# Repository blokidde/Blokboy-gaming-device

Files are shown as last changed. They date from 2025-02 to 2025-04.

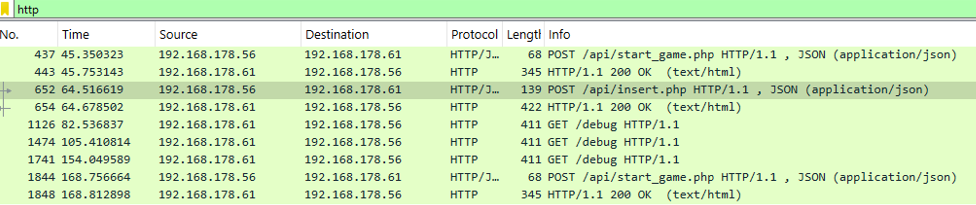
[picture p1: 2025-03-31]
docs/assets/http_messages.png

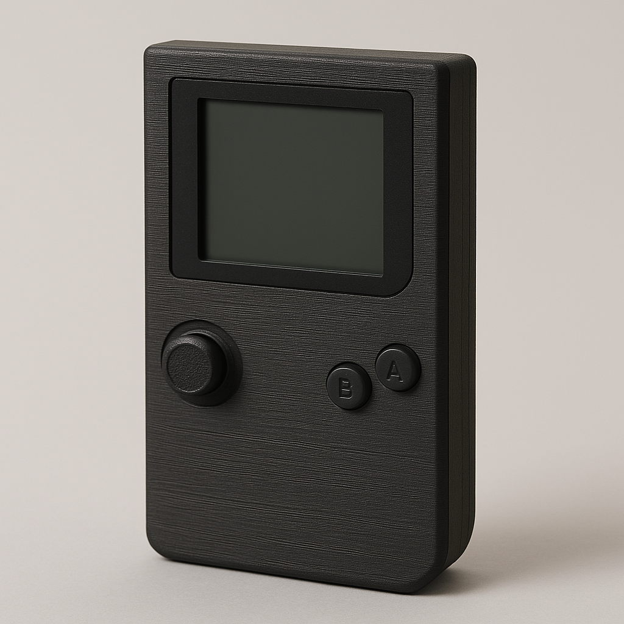
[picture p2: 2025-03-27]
docs/assets/3d_generated_blockboy_picture.png

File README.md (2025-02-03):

# IoT Start Project

This is your IoT Gitlab project. You can use it to store your code and documentation. 

## Getting Started

This project contains a setup using Docker. This will help you setup all the necessary tools to start developing your IoT project.
Before you run the docker-compose command, make sure you have to make changes to the configuration. You can find these in
the `.env` file.

Now, to install and start your project; run the following command in the root of your project:

```bash
docker-compose up -d
```

If everything runs correctly, you should be able to visit your website at [http://localhost/](http://localhost/).

## Structure

There is a specific structure that you should follow when developing your project. This will help you to keep your project organized and easy to understand.

**Documentation**

All the documentation of your project should be placed in the `docs/` folder. This will be used for your portfolio-website.

```bash
├── docs/
```

**Embedded**

Everything you need to run your embedded application should be placed in the `embedded/` folder. This includes the source code like .ino-files from Arduino.

```bash
├── embedded/
```

**Web**

Everything you need to run your web application should be placed in the `web/` folder. This includes the source code like PHP, HTML, CSS, Javascript and images.

```bash
├── web/
```

You can visit your website by going to [http://localhost/](http://localhost/) in your browser. And you can find your IoT dashboard at [http://localhost/dashboard](http://localhost/dashboard).

## Database details

The database is a MySQL database using MariaDB. You can connect to it using the following details:

| Parameter | Value |
| --- | --- |
| Host | `mariadb` (from PHP) `localhost` (from your laptop) |
| Port | `3306` |
| Username | `root` |
| Password | You can find this in your .env-file. |
| Database | You need to create the database yourself. |

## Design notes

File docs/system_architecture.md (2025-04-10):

# System Architecture

## Introduction
This section provides an overview of the entire IoT Snake Game setup. It explains each hardware and software component and how they communicate.

## Legend
- Rectangles: Subsystems or containers  
- Components: Smaller software units (for example, code files and libraries)  
- Database symbol: Data storage  
- Cloud symbols: External systems (for instance, GitLab or the Internet)  
- Arrows: Show direction of data and the communication protocols (HTTP, MySQL, etc.)

## Architecture Diagram
The following image shows the System Architecture Diagram for the IoT Snake Game. Each subsystem is labeled, and communication lines show which protocols and ports are used.

Architecture_Diagram

## Subsystems and Components

1. User Device (Mobile / Laptop)  
   - Runs a Browser that displays the frontend (HTML, CSS, JavaScript).  
   - Sends HTTP debug requests to the ESP32.  
   - Receives pages and data from the NGINX web server (HTTPS).

2. Host System (PC / Laptop)  
   - Runs the Docker Host with multiple containers (NGINX, PHP, MariaDB, phpMyAdmin).  
   - Connects to GitLab (external repository) and the Docker Registry (external system) to pull Docker images.  
   - Uses the Host OS (Windows/Linux) as the operating system.

3. Web Server (NGINX)  
   - Main entry point for HTTPS traffic from the browser.  
   - Hosts the Frontend (HTML, CSS, JS files).  
   - Routes API calls to the Backend (PHP scripts).

4. Backend (PHP API)  
   - Handles requests via API PHP files (for example, insert.php, get.php).  
   - Uses Backend Libraries (native PHP functions or extensions) to process data.  
   - Connects to the database for storing and retrieving game information.

5. Database System  
   - Runs inside the MariaDB Container.  
   - Holds the MariaDB Database and the Database Instance (actual data).  
   - Stores player scores and any other relevant game data.

6. Embedded System (ESP32)  
   - Written in C++ with Arduino Libraries.  
   - Contains the Game Logic for the Snake Game and an HTTP Client for sending and receiving data.  
   - Interfaces with the Joystick, Button, Buzzer, and TFT Display.

7. External Systems  
   - Internet / Intranet: Used for network communication (HTTPS, etc.).  
   - GitLab Repository: Stores the project code (external system).  
   - Docker Registry: Hosts Docker images (external system).

## Communication Protocols
- HTTPS (443): Browser to NGINX (secure)  
- HTTP (80): ESP32 to Backend or for debug requests  
- MySQL (3306): Backend (API) to database  
- SPI: ESP32 to TFT display  
- Analog / Digital: Joystick and button inputs  
- PWM: Buzzer output from ESP32

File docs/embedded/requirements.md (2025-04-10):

# Requirements

# requirements EMBRQ#01
The embedded device acts as a client and sends measured sensor data to the application backend over http or https.

## EMBRQ#01
The ESP32 sends sensor data to a webserver using HTTPS. It acts like a client and sends the number of times the joystick was moved up, down, left, and right. This is done using WiFi and a POST request. The data is sent as a JSON string to the backend. more aboout this can be read in the research page

### Code:
```cpp
WiFiClientSecure client;
client.setInsecure();

HTTPClient httpClient;
httpClient.begin(client, url);

StaticJsonDocument<200> doc;
doc["totalup"] = totalup;
doc["totaldown"] = totaldown;
doc["totalleft"] = totalleft;
doc["totalright"] = totalright;

String jsonString;
serializeJson(doc, jsonString);

int httpcode = httpClient.POST(jsonString);
```

# requirements EMBRQ#02
The embedded device also acts as a server and receives status messages from the application backend over http or https.

## EMBRQ#02
The ESP32 works as a server. It waits for HTTP requests from the backend. When the backend sends a request to the /debug endpoint, the ESP32 sees this and runs the debug() function. This way, it can receive status messages or commands from the backend over HTTP.

### code
```cpp
WiFiClient client = server.available();

if (client) {
  String request = "";
  while (client.available()) {
    char c = client.read();
    request += c;
    if (c == '\n') break;
  }

  if (request.indexOf("GET /debug") >= 0) {
    debug();
  }
}
```

# requirements EMBRQ#03
The embedded device contains at least two types of input sensors (e.g. LDR, buttons, joystick, capacitive touch, etc.).

## EMBRQ#03
The ESP32 uses two types of input sensors:
- A joystick to control the snake's movement (up, down, left, right).
- Buttons to interact with the game, like starting or restarting.

The joystick is read using analog input pins, and the buttons are read using digital input pins.

### code
example of joystick code:
```cpp
if (vert < DOWNTHRES && snake.direction_y != -1) {
    snake.direction_x = 0;
    snake.direction_y = 1;
}
```

example of button code:
```cpp
while(digitalRead(BUTTON_2_PIN)){
    delay(20);
}
```

# requirements EMBRQ#04
The embedded device contains at least two types of visual and/or sensory outputs (e.g. LED, LED Matrix, 7-segment display, motor, servo, actuator, LCD-screen, buzzer, etc.).

## EMBRQ#04
The ESP32 has two types of outputs:

- An lcd display (ILI9341) that displays the snake game
- A piezo buzzer that makes sound during the debug test and during the game

### code
example for display:
```cpp
Adafruit_ILI9341 display = Adafruit_ILI9341(TFT_CS, TFT_DC, TFT_RST);

display.setTextSize(1);
display.setTextColor(ILI9341_WHITE);
display.fillScreen(ILI9341_BLACK);
```
example for buzzer:
```cpp
tone(BUZZER_PIN, 1000, 100);
```

## requirements EMBRQ#05

The embedded device uses the WifiManager for configuration of SSID and password (PWD) for connecting to the network.

## EMBRQ#05
The esp32 connects to wifi using the wifimanager, it does this by first initializing the library:

### code
```cpp
#include <WiFiManager.h>
```
then the wifimanager checks if it can connect with the wifi with this while loop:
```cpp
if (!wifiManager.autoConnect("ESP32-Setup")) {
  Serial.println("Failed to connect, restarting...");
  delay(3000);
  ESP.restart();
}
```
if it cannot connect, the wifimanager starts a web portal through which you can input the correct wifi.

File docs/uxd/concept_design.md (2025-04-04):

# Concept & Design prototype

## Main goal
the main goal of this project is:  
create a handheld gaming device for playing snake with physical inputs and automatic data tracking, that is fully 3d-printable and works wirelessly. 

## concept
im going to try to make the design look a little like an old gameboy. for designing i used the tool Freecad.

## user description
the user is someone who wants to play a classic snake game on a physical, handheld gaming devie. the user wants to get instant feedback from joystick and button inputs and view scores after a game. the device needs to be small, portable, and easy to charge.

## user needs
- the device must be compact and handheld
- it must feel like an oldschool gameboy
- it must be possible to track gameplay stats
- scores must be sent to a database
- the data should be viewable in a simple online dashboard
- the device must be easy to assemble without tools or glue
- a battery must fit inside so it's fully portable

## product requirements
- the joystick must fit perfectly in the joystickhole
- the screen must be fully visible and centered
- the screen must fit well into the hole, wihtout falling out
- two breadboards with ESP32 and battery must fit inside the case
- the buzzer must fit perfectly in the buzzer hole
- the power button must be accessible from the outside
- all components must be powered by a single li-ion 18650 battery

## first design

frontpanel design:

frontpanel design

in the design for the frontpanel i created several holes. one for the screen, one for the joystick, two push buttons, and an on off button. 

backpanel design:

frontpanel design

on the backpannel you can see two indents, these indents are for 2 breadboards with an esp32 on it and for a li-ion 18650 battery. 

the front and backpanel are suposed to slot together without any glue or screws.

## current design
after 5 iterations of the frontpanel and 2 iterations of the backpanel, all the 3d prints are done and they fit.
the changes that were made are:
- screw pillars
- smaller joystick hole
- bigger on off hole
- direction of screen has changed
- size of screen has changed
- bigger buzzer hole
- bigger battery placement hole

this is the frontpanel:

frontpanel design

this is the backpanel:

frontpanel design

## tools used
for the design part of the project, the following tools and settings were used:

- Freecad for 3d modeling
- exported as STL for slicing
- printed using an Ultimaker 2+ and bambu lab carbon x1 (standard settings)
- filament used: PLA
- layer height: 0.2 mm
- infill: 20%
- supports: only for frontpanel, using the tree support style

i used Freecad because it is open-source and allows full control over design with a nice GUI. this made it easy to quickly change measurements like hole sizes and panel thicknesses during each design.

## recreatability
the device is designed to be fully recreatable:
- freecad files include all versions
- printed with standard PLA and normal 3d printer
- component placement is visible in the 3d model

## versions
### frontpanel
- v1 
- v2 changed sizes for components
- v3 changed small things for component sizes
- v4 rotated display hole, lowered the button holes
- v5 bigger hole for joystick and display, added thicker screw holes

### backpanel
- v1
- v2 more centered and bigger battery hole

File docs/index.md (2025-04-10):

# Blokboy gaming device

This project is a modern version of the classic game called Snake, built with an ESP32 microcontroller and an display. The player controls the snake using a joystick, while their movement data and scores are automatically sent to a server via WiFi.

The web interface displays a scoreboard, showing player IDs and scores in a clean, responsive design. A dedicated debug button allows real-time communication with the ESP32 for testing or troubleshooting. All data is handled through the API and stored in a database, creating a smooth and connected gaming experience.

{{ mdocotion_header('https://images.unsplash.com/photo-1550745165-9bc0b252726f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') }}

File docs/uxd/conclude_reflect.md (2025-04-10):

# Conclude & Reflect

## reflection

### general reflection
this project started with the idea of building a small handheld snake game device that looks like a gameboy. the goal was to make the casing fully 3d printable, without the use of glue or screws, and to make it feel like a polished physical product. through multiple design iterations and test prints, the device became more and more refined. the final result is a working handheld game that is portable, solid, and replicable.

working with Freecad gave me a lot of flexibility, small changes to dimensions were quick and didn’t require starting over completely. 3d printing allowed me to test the physical feel and fit of components in real life, which helped improve the finalization of the design. 

### recommendations for improvements
- improve joystick fit and rotation quality using a custom joystick mount or printed bearing system
- use buttons with larger caps to improve button clarification
- add a small indicator led or animation to show when the device is booting

### failures

#### 1. joystick fit
goal: i wanted the joystick to move freely in all directions without friction  
what went wrong: i made the hole have the same dimensions as the joystick and it was way too big  
how i tried to solve it: i printed several versions with decreased hole diameter  
next time: i would test joystick tolerances with calipers first check the total movement it will need

#### 2. screen visibility
goal: i wnated to create pillars for the joysticks pcb to be attached to  
what went wrong: i created pillars for screws that were too thin   
how i tried to solve it: i made the pillars thicker
next time: i would measure the thickness of the screws i want to use first.

#### 3. first print
goal: i wanted to print my first 3d print
what went wrong: when i tried to print, the fillament didnt stick to the floormat  
how i tried to solve it: i got a teacher to calibrate the 3d printer
next time: there is unfortunately notihing that could be changed about this

#### 4. display spacing
goal: i wanted to put the display in the casing vertically
what went wrong: when i tried to put the display in, it did not fit
how i tried to solve it: i printed a new iteration with the display horizontally

#### all iterations next to eachother
this picture shows all the different iterations starting with the gray ones(bottom) and ending with the final product with the components installed and wired. more can be found about the iterations in the concept design page.

iterations

### final result

the final product works as intended. all parts fit together tightly. the game can be played with the joystick and buttons, and scores are saved. the product feels solid in the hand and can be used without instructions(except for the buttons).

- the layout of all the components feels natural
- the casing is printable with common settings
- the product is replicable with all provided files and settings

the product is clean and usable. it meets the defined requirements and can be easily printed and assembled by others. it only needs a few more changes/ iterations before the product would be very good.

### final product pictures
the product from the front, you can see the display, joystick and buttons: 

prod front

the product when its open:

prod open

the product from the left, you can see the buzzer on the side:

prod left

the product from the right, you can see the on off button:

prod right

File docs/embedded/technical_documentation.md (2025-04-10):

# Technical documentation

## Wiring Diagram
below you can find the wiring diagram for the blockboygamingdevice, it is made in kicad, the red lines are the vcc (+) and the black lines are the ground (-). there are also several components in the wiring diagram, these all have fitting names that can be found in the wiring diagram

wiring diagram

## Bill of Materials prototype

this is a bill of materials, in this BOM is the information about all the materials used for the prototype of the Blockboy gaming device.

| Part # | Manufacturer  | Description | Quantity | Price | Subtotal | website for product |
|---|---|---|---|---|---|---|
| ILI9341 | Adafruit | 320x24 lcd display | 1 | EUR 10,95 | EUR 10,95 | [Link](https://www.otronic.nl/nl/mini-oled-display-wit-096-inch-128x64-i2c.html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) |
| KY-023 | Keyes | Joystick Module | 1 | EUR 2,50 | EUR 2,50 | [Link](https://www.otronic.nl/nl/joystick-module.html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) |
| PBS-110 | Omron | Push Button Switch | 2 | EUR 0,10 | EUR 0,20 | [Link](https://www.tinytronics.nl/nl/schakelaars/manuele-schakelaars/printplaatschakelaars/tactile-pushbutton-switch-momentary-4pin-6*6*5mm) |
| SFM-20B | unknown | Piezo Buzzer - 3900-5000 Hz | 1 | EUR 1,25 | EUR 1,25 | [Link](https://www.hobbyelectronica.nl/product/piezo-elektronische-zoemer-sfm-20b/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) |
| ESP32 |  espressif  | ESP32 microcontroller | 1 | EUR 11,99 | EUR 11,99 | [Link](https://www.amazon.nl/Diymore-DevKitC-ontwikkelboard-Bluetooth-gesoldeerd/dp/B0CYZVQR27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) |
| Li-ion battery | surefire | 3.7v battery 2600mAh | 1 | EUR 8,5 | EUR 8,5 | [Link](https://www.kabeldirect.nl/bse-li-on-cr-18650-batterij-3.7v-2600-mah-met-buttontop.html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) |
|on/off switch | unknown | on/off switch | 1 | EUR 1,19 | EUR 1,19 | [Link](https://www.allekabels.nl/schakelaar/7303/1063954/wipschakelaar.html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) |

### connection Wiring Diagram & Bill of Materials
| Wiring Diagram | Bill of Materials |
|---|---|
| ESP32-S3-WROOM-1 | ESP32 |
| CR2013-MI2120 | ILI9341 |
| R_Potentiometer_Dual  | KY-023 |
| SW_Push  | PBS-110 |
| SW_Push  | PBS-110 |
| Buzzer | SFM-20B |
| Battery_Cell | 3.7V Li-ion Battery |
| SW_SPST | On/Off Switch |

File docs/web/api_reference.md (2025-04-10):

# API reference

## API/ESP32

### API
The API handles communication between the ESP32 and the database. The ESP32 sends data to the API using an HTTP request, formatted as a JSON file. The API processes this data and stores it in the database for further analysis.

### ESP32
The ESP32 collects joystick movement data and sends it to the API through an HTTP POST request. This allows the system to track player input and use it for game analytics or debugging.

## API endpoints

### POST post.php
The API receives joystick input from the ESP32 and stores it in a database.

#### request
- Method: POST
- Content-Type: application/json
- Body: JSON formatted data containing joystick movement counts.

#### request format
```json
{   
    "game_id": 31,
    "totalup": 5,
    "totaldown": 3,
    "totalleft": 2,
    "totalright": 4,
    "score": 9
}
```

### POST start_game.php
The API receives a player ID and creates a new game session for that player in the database. It returns the newly created game ID.

#### request
- Method: POST
- Content-Type: application/json
- Body: JSON formatted data containing the player ID.

#### request format
```json
{
  "player_id": 3
}
```

### GET get.php
The API retrieves all recorded scores from the database along with the corresponding player IDs. This endpoint is used by the frontend to display the current scores of all players.

#### request
- Method: GET
- No request body required.

#### response format
Returns a JSON array of score entries. Each entry contains:
- player_id: the ID of the player
- score_value: the score they achieved

#### example response
```json
[
  {
    "player_id": 1,
    "score_value": 45
  },
  {
    "player_id": 2,
    "score_value": 60
  }
]
```

#### response codes
if correctly sent, code: 200

if not sent correctly code of: -1

if the request doesnt have the correct fields: 400

if there is an issue with the database: 500

### functionality
The ESP32 sends joystick movement data to the API at regular intervals or after a game session.
The API validates the incoming JSON data and makes sure all required fields are in the json.
If the data is correct, it is inserted into the database, storing player movements for use in the website.
The API responds with a success or error message, allowing the ESP32 to confirm whether the request was processed correctly.

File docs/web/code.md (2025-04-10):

# Web Code

## Web development
### Modern Web Standards
This web application uses modern web development principles:
- JavaScript fetch() for all API calls
- Clean separation (HTML for structure, CSS for style, JS for logic)
- Responsive styling with CSS
- All data is dynamically loaded via JavaScript without reloading the page

## PHP
### db_connect.php
a single file for connecting to the database using mysqli. this file is used in all the other php files.

### get.php
Returns a list of all game scores stored in the database by connecting to the database, executing a SQL query with SELECT, returns a JSON array.

### insert.php
Receives statistics from the ESP32 and puts them into the database.
```json
{
  "game_id": 123,
  "totalup": 10,
  "totaldown": 8,
  "totalleft": 5,
  "totalright": 7,
  "score_value": 15
}
```
this is what the expected json looks like, the function parses this, validates it and puts it into the score table with and INSERT INTO query

### start_game.php
Creates a new game entry in the database and returns a game_id and player_id to the ESP32. This will then later be used for the insert.php function

the json that is sent first looks like this:
```json
{ "generate": 1 }
```
it then get a json back that looks like this if the first POST is succesful:

```json
{
  "status": "success",
  "player_id": 42,
  "game_id": 101
}
```

## JavaScript
JS handles the communication between the webpage and the server (PHP backend) as well as sending debug requests to the ESP32 device.

### fetchScores()
This function retrieves all game scores from the backend API (get.php) and dynamically updates the HTML table.
```JS
fetch('api/get.php')
.then(response => response.json())
.then(data => {
// Updates DOM with new data
});
```
this function first makes a GET request to the get.php endpoint. afther this is parses the json and updates the table with the data.

### sendRequestToEsp32()
This function sends a debug request to the ESP32 device.

```JS
fetch('https://145.109.225.167/debug', { method: 'GET' })
```

makes a GET request to the esp32's ip address webserver

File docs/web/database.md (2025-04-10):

# Database

## Database EERD
ERD
## Tables

### players

| Field | Type | Description |
|---|---|---|
| player_id | INT (PK) | Unique player identifier |
| created_at  | TIMESTAMP | Timestamp of creation |

### games

| Field | Type | Description |
|---|---|---|
| game_id | INT (PK) | Unique game session ID |
| player_id | INT (FK) | Links to player |
| start_time  | TIMESTAMP | Game start time |

### scores

| Field | Type | Description |
|---|---|---|
| score_id | INT (PK) | Unique score ID |
| game_id | INT (FK) | Links to game |
| score_value  | INT | Score earned in game |

### sensor_data

| Field | Type | Description |
|---|---|---|
| sensor_id | INT (PK) | Unique sensor entry |
| game_id | INT (FK) | Links to game |
| direction | VARCHAR(10)  | 'up', 'down', 'left', or 'right' |
| total_moves | INT | Number of directional movements |
| timestamp | TIMESTAMP | When this sensor data was recorded |

## choice for keys and candidate keys
For each table, i considered natural keys vs surrogate keys. i chose auto-incremented integers (INT) as primary keys because:

- They are efficient
- Easy to reference in foreign keys

No candidate keys existed in the sensor_data table.(game_id, direction) were considered, but this would prevent several entries for the same direction.

## Relationships

- One `player` can have many `games`
- Each `game` has one `score`
- Each `game` can have many `sensor_data` entries

## Normalization

- The database is normalized to 3rd Normal Form (3NF).
- No redundant data across tables.
- All non-key attributes depend on the full primary key.
- Relationships are clean and maintainable.

## Sensor Data Flexibility

The current system gets four directional inputs from a joystick:
- up
- down
- left
- right

however it is fairly easy to add more sensor data to this table without modifying the schema.

## SQL implementations

```sql
INSERT INTO players (player_id, created_at) VALUES (1, NOW());
INSERT INTO games (game_id, player_id, start_time) VALUES (1, 1, NOW());
INSERT INTO scores (score_id, game_id, score_value) VALUES (1, 1, 45);
INSERT INTO sensor_data (sensor_id, game_id, direction, total_moves, timestamp) VALUES
(1, 1, 'up', 15, NOW()),
(2, 1, 'down', 10, NOW()),
(3, 1, 'left', 5, NOW()),
(4, 1, 'right', 20, NOW());
```

## how to use database
1. Open MySQL Workbench.
2. Copy the full SQL code below.
3. Paste it into a new SQL tab.
4. Run the script to create the schema, tables, and relationships.

link to sql file: 
[Link](https://gitlab.fdmci.hva.nl/IoT/2024-2025-semester-2/individual-project/teemiixuujuu34/-/blob/main/database/mydatabase.sql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)
```sql
-- MySQL Workbench Forward Engineering

SET @OLD_UNIQUE_CHECKS=@@UNIQUE_CHECKS, UNIQUE_CHECKS=0;
SET @OLD_FOREIGN_KEY_CHECKS=@@FOREIGN_KEY_CHECKS, FOREIGN_KEY_CHECKS=0;
SET @OLD_SQL_MODE=@@SQL_MODE, SQL_MODE='ONLY_FULL_GROUP_BY,STRICT_TRANS_TABLES,NO_ZERO_IN_DATE,NO_ZERO_DATE,ERROR_FOR_DIVISION_BY_ZERO,NO_ENGINE_SUBSTITUTION';

-- -----------------------------------------------------
-- Schema mydb
-- -----------------------------------------------------

-- -----------------------------------------------------
-- Schema mydb
-- -----------------------------------------------------
CREATE SCHEMA IF NOT EXISTS `mydb` ;
USE `mydb` ;

-- -----------------------------------------------------
-- Table `mydb`.`Player`
-- -----------------------------------------------------
CREATE TABLE IF NOT EXISTS `mydb`.`Player` (
  `player_id` INT(11) NOT NULL AUTO_INCREMENT,
  `username` VARCHAR(50) NULL DEFAULT NULL,
  `created_at` TIMESTAMP NULL DEFAULT CURRENT_TIMESTAMP(),
  `generate` TINYINT(1) NOT NULL DEFAULT 0,
  PRIMARY KEY (`player_id`),
  UNIQUE INDEX `player_id_UNIQUE` (`player_id` ASC) VISIBLE)
ENGINE = InnoDB
AUTO_INCREMENT = 72;

-- -----------------------------------------------------
-- Table `mydb`.`CurrentGame`
-- -----------------------------------------------------
CREATE TABLE IF NOT EXISTS `mydb`.`CurrentGame` (
  `game_id` INT(11) NOT NULL AUTO_INCREMENT,
  `player_id` INT(11) NOT NULL,
  `started_at` TIMESTAMP NULL DEFAULT CURRENT_TIMESTAMP(),
  `ended_at` TIMESTAMP NULL DEFAULT NULL,
  PRIMARY KEY (`game_id`),
  INDEX `fk_currentgame_player_idx` (`player_id` ASC) VISIBLE,
  CONSTRAINT `fk_currentgame_player`
    FOREIGN KEY (`player_id`)
    REFERENCES `mydb`.`Player` (`player_id`)
    ON DELETE CASCADE
    ON UPDATE CASCADE)
ENGINE = InnoDB
AUTO_INCREMENT = 73;

-- -----------------------------------------------------
-- Table `mydb`.`JoystickInput`
-- -----------------------------------------------------
CREATE TABLE IF NOT EXISTS `mydb`.`JoystickInput` (
  `joystick_id` INT(11) NOT NULL AUTO_INCREMENT,
  `game_id` INT(11) NOT NULL,
  `totalup` INT(11) NOT NULL,
  `totaldown` INT(11) NOT NULL,
  `totalright` INT(11) NOT NULL,
  `totalleft` INT(11) NOT NULL,
  `created_at` TIMESTAMP NULL DEFAULT CURRENT_TIMESTAMP(),
  PRIMARY KEY (`joystick_id`),
  INDEX `fk_joystick_game_idx` (`game_id` ASC) VISIBLE,
  CONSTRAINT `fk_joystickinput_game`
    FOREIGN KEY (`game_id`)
    REFERENCES `mydb`.`CurrentGame` (`game_id`)
    ON DELETE CASCADE
    ON UPDATE CASCADE)
ENGINE = InnoDB
AUTO_INCREMENT = 58;

-- -----------------------------------------------------
-- Table `mydb`.`Score`
-- -----------------------------------------------------
CREATE TABLE IF NOT EXISTS `mydb`.`Score` (
  `score_id` INT(11) NOT NULL AUTO_INCREMENT,
  `game_id` INT(11) NOT NULL,
  `score_value` INT(11) NOT NULL,
  `created_at` TIMESTAMP NULL DEFAULT CURRENT_TIMESTAMP(),
  PRIMARY KEY (`score_id`),
  INDEX `fk_score_game_idx` (`game_id` ASC) VISIBLE,
  CONSTRAINT `fk_score_game`
    FOREIGN KEY (`game_id`)
    REFERENCES `mydb`.`CurrentGame` (`game_id`)
    ON DELETE CASCADE
    ON UPDATE CASCADE)
ENGINE = InnoDB
AUTO_INCREMENT = 58;

SET SQL_MODE=@OLD_SQL_MODE;
SET FOREIGN_KEY_CHECKS=@OLD_FOREIGN_KEY_CHECKS;
SET UNIQUE_CHECKS=@OLD_UNIQUE_CHECKS;

```

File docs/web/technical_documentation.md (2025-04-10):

# Technical Documentation

## System Overview

This project connects an ESP32-based game device to a backend system using a RESTful API built in PHP. The backend stores gameplay and sensor data in a MySQL database, while the frontend displays game statistics and allows for remote interaction with the device.

### Components

| Component | Technology | Reason for Use |
|---|---|---|
| Embedded Device | ESP32 Microcontroller  | Lightweight, powerful, and WiFi-capable |
| Frontend | HTML, CSS, JavaScript  | Simple and accessible web interface |
| Backend API | PHP | Lightweight, widely supported, and easy to integrate |
| Database | MySQL/MariaDB | Robust, relational storage with easy PHP integration |

## Design Decisions

- Technology choice: PHP was chosen because it's easy to use and works well with ESP32 POST requests. MySQL was selected for its reliability and widespread use.
- REST structure: Each endpoint performs one action only (POST to insert, GET to fetch, etc.), following RESTful principles.
- Modular schema: The database is designed with normalized, extensible tables to allow easy addition of future sensor types.

## Problems Encountered and Solutions

- issues during development: Solved by adding appropriate headers in PHP (Access-Control-Allow-Origin:).
- HTTPS certificate verification: ESP32 had trouble with HTTPS, solved by using client.setInsecure() for development.
- Data mismatch: Validations were added in PHP to ensure JSON data contains all required fields before insertion.

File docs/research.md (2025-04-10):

# how can i make the connection between client and server safer?

### subquestions/parts
- [Introduction](#Introduction)
- [What are the differences http and https](#What-are-the-differences-http-and-https)
- [How does https improve the safety?](#How-does-https-improve-the-safety)
- [What do i need to upgrade http to https?](#What-do-i-need-to-upgrade-http-to-https)
- [How do i test the upgraded safety?](#How-do-i-test-the-upgraded-safety)
- [Why is security important?](#Why-is-security-important)
- [Are there issues that arise from switching to https?](#Are-there-issues-that-arise-from-switching-to-https)
- [Research method](#Research-method)
- [Conclusion](#Conclusion)
- [Sources](#Sources)

## Introduction
HTTP stands for hypertext transfer protocol. It is used to send information over the internet between a client and a server. However HTTP is not secure, this means anyone can see the message sent. This is ofcourse sub optimal for safety reasons.
https://www.cloudflare.com/learning/ddos/glossary/hypertext-transfer-protocol-http/

HTTPS stands for hypertext transfer protocol secure. It is the upgraded version of HTTP, it uses something called TLS, which stands for transport layer security. This is an encryption program, it encrypts the message sent between client and server.This encryption makes sure that outsiders cannot read or change the data, even if/when they manage to intercept it.
https://www.ssl.com/faqs/what-is-https/

By upgrading HTTP to HTTPS, a layer of security is added. When someone tries to look at the message sent from client to server through a program like wireshark they can see the entire HTTP message plain as day. With HTTPS you could only see an encrypted message.

For developers working on web-based applications, projects using web servers or any other IOT projects, security is essential. Whether you're building a scoreboard system, a login form, or controlling hardware remotely, upgrading from HTTP to HTTPS adds a necessary layer of protection.

This upgrade improves not only the security of the system, but also trustworthiness, if others will interact with or use the application. It shows the developer cares about data privacy and modern web standards.

## What are the differences http and https

| Feature | HTTP | HTTPS |
|---|---|---|
| Full Name | HyperText Transfer Protocol | HyperText Transfer Protocol Secure |
| Security | Not secure (data is sent as normal text) | Secure (data is encrypted) |
| Data Protection | Anyone on the network can read or modify the data| Only the sender and receiver can read the data |
| Port | Uses port 80 by default | Uses port 443 by default |
| URL Prefix | http:// | https:// |
| SSL/TLS Certificate | Not required | Required for encryption and identity verification |
| Browser Lock Icon | No lock icon, or shows "Not secure" | Shows a lock icon in the address bar |
| Performance | Slightly faster, but vulnerable | Slightly slower due to encryption, but safe |
| SEO & Trust | Lower SEO ranking; users may be warned | Better SEO ranking; users trust it more |
https://chatgpt.com/

## how does https improve the safety?
HTTPS improves the safety of communication between a client and a server in three important ways: encryption, authentication, and data integrity. This protection is made possible by using TLS (Transport Layer Security), a protocol that ensures data is transferred securely over the internet.

### Encryption
ensures that the data sent from the client to the server is scrambled into unreadable characters. When using HTTP, this data is sent as plain text, meaning anyone on the same network — for example, using a program like Wireshark — can easily read it. This is dangerous when sending sensitive information like usernames, scores, or commands to a device. With HTTPS, the data is encrypted, so even if someone intercepts it, they will only see unreadable characters. This keeps the content of the communication private and secure.

### Authentication
Authentication ensures that the client communicates with the intended server, preventing attacks such as man-in-the-middle attack. HTTPS uses SSL/TLS certificates issued by trusted third-party authorities to verify the identity of servers. When connecting, the server presents its certificate, allowing the client to verify that the server is authentic and trusted.

### Data integrity
Data integrity ensures that messages exchanged between client and server cannot be altered during transmission. HTTPS, via TLS, includes integrity checks that detect any attempts to modify data packets while being sent. If data manipulation is detected, the connection is terminated, protecting the transmitted information from being changed by unauthorized people.

## What do i need to upgrade HTTP to HTTPS?
to upgrade you need at least these things:
- tls(ssl) certificate
- https capable server
- updated URL's

## How do i test the upgraded safety?
### HTTP
http_wireshark
here we see a wireshark screenshot with a few important parts. this is a http message that was sent from the ESP32(server) to the API. on the right bottom side we see the exact json message that was sent through http:

http_json

on the left bottom side are a few pieces of information about the message like the length, amount of bytes and bits and the protocols used:

http_message_info

on the top you can see several different http messages, all of these were sent between server and client and the content can be easily read:

http_top

### HTTPS

This is a Wireshark capture using HTTPS. The content is encrypted, showing only "Encrypted Application Data":

https_top

Encrypted HTTPS message, showing no readable info(the higlighted part is the encrypted message):

https_message_encoded

This shows the extra safety with HTTPS.

## Why is security important?
Security is important because the internet can be a dangerous place. Without good security, people with bad intentions can easily access your personal information or interfere with your systems. They might steal data, such as passwords or bank information, change your data, or even completely disrupt how your system works. This can lead to serious issues like identity theft, loss of money, damage to your reputation, or a loss of trust from your users.

A common attack is a man-in-the-middle attack (MITM). In a MITM attack, an attacker secretly sits between two people (or a device and a server) communicating over the internet. The attacker can read, copy, or even change the information being exchanged, all without either side noticing. To prevent MITM attacks, developers use encryption (like HTTPS) and certificates that ensure both sides are who they say they are.
https://www.cloudflare.com/learning/security/threats/man-in-the-middle-attack/

Another type of attack is called SQL injection. This happens when attackers use insecure input fields (like forms on websites) to send harmful instructions directly to a database. If these fields aren’t properly secured, attackers could access private data, delete or modify important information, or even take control of entire database. Preventing SQL injection involves carefully checking user input and using secure programming techniques to avoid letting attackers send illegal instructions.
https://portswigger.net/web-security/sql-injection

## Are there issues that arise from switching to https?
Switching from HTTP to HTTPS can give a few small problems like:
- setup is more difficult
- slower performance
- certificate renewal
https://chatgpt.com/

## Research method

To answer the research question, I looked at how HTTP and HTTPS work using both online sources and my own testing. I first tested an HTTP connection between my ESP32 and a local server, then captured the traffic using Wireshark. I repeated the test after upgrading to HTTPS and compared the results. This showed exactly what part of the message is visible and how that changes when encryption is used.

Next to testing, I also read multiple sources like Cloudflare, SSL.com, and OWASP to understand how encryption works, what kind of attacks HTTPS protects against, and how HTTPS is implemented in web applications and IoT projects.

## Conclusion

The main question was: How can I make the connection between client and server safer?

After comparing HTTP and HTTPS, reading about encryption methods, and testing it with Wireshark, I can say that HTTPS is the best option to make the connection safer. It protects the data in three ways: encryption, authentication, and data integrity. These make it much harder for attackers to read or change the data during transport.

I also found out what is needed to set up HTTPS: a TLS certificate, an HTTPS-capable server, and updated URLs in the client code. Testing with Wireshark clearly showed that with HTTP, the whole message is visible, but with HTTPS, the data is fully encrypted and unreadable for others on the network.

Some small downsides exist, like more setup time and performance cost, but the safety it adds is much more important. Security is especially needed in IOT or web projects where data is sent over the internet.

### Sources
- https://www.cloudflare.com/learning/ddos/glossary/hypertext-transfer-protocol-http/
- https://www.ssl.com/faqs/what-is-https/
- https://chatgpt.com/
- https://owasp.org/www-project-top-ten/
- https://www.cloudflare.com/learning/security/threats/man-in-the-middle-attack/
- https://portswigger.net/web-security/sql-injection

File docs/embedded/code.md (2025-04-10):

# Embedded code

## important library's

```cpp
#include <Adafruit_GFX.h>
#include <Adafruit_ILI9341.h>
```

these libraries are used for the ILI9341 display
```cpp
#include <HTTPClient.h>
#include <WiFiClientSecure.h>
#include <ArduinoJson.h>
```
these libraries are used for the https requests, the arduinojson lib is used to create 

```cpp
#include <WiFi.h>
```
this library is used for connecting wifi

## functions

### `void setup()`
in this function we set the outputs and inputs for the entire program like this `pinMode(VERT_PIN, INPUT);`, we also connect with necessary things like wifi using this:
```cpp
WiFiManager wifiManager;
if (!wifiManager.autoConnect("ESP32-Setup")) {
  Serial.println("Failed to connect, restarting...");
  delay(3000);
  ESP.restart();
}
```
for the initialization of the display we use this:
```cpp
SPI.begin(TFT_CLK, -1, TFT_MOSI);
display.begin();
```

### void `snakeInit()`
the snake init function is used to initialize everything needed for the snake and the first apple. first there are some variables that are set to false or 0
```cpp
 game_over = false;
  score = 0;
  totalup = 0;
  totaldown = 0;
  totalleft = 0;
  totalright = 0;
```
after this the function starts by setting the values in the struct called snake. `snake.length = 1;`the length of the snake is set to 1. this is done for several different parts of the snake struct. values for the apple struct are also set using the same principle.

### void creategame()
the creategame function clears the screen, draws the apple at its position, draws each segment of the snake, and finally updates the display so you can see everything on the OLED screen. It uses a grid system, so it multiplies the apple’s and snake’s coordinates by the block size to place them at the right spots in pixels.

```cpp
display.fillRect(applex, appley, BLOCKSIZE, BLOCKSIZE, ILI9341_RED);
```
this code is used to create apples, in the code we use blocksize. the block size is the size of every object. this is done so that the snake and apple arent way too small. the block size is 8, the ILI9341 is 320x240 pixels

```cpp
for (int i = 0; i < snake.length; i++)
{
  int x = snake.segments[i].x * BLOCKSIZE;
  int y = snake.segments[i].y * BLOCKSIZE;
  display.fillRect(x, y, BLOCKSIZE, BLOCKSIZE, ILI9341_GREEN);
}
```
this code uses the same principle to create the starting segments of the snake. they are also made from blocks that are 8x8 pixels.

### void drawSnake()
The drawSnake function moves the snake’s head in its current direction and checks if it hits a wall or its own segments. If it eats an apple, the snake grows longer and the apple is moved to a new random location. Otherwise, it just moves forward. If the snake collides with anything, the game ends.

```cpp
int newHeadX = snake.segments[0].x + snake.direction_x;
int newHeadY = snake.segments[0].y + snake.direction_y;
```
in this code snippet you can see how the new head of the x and y are calculated. first you take the first point of the segments array. this is the old head position. after this you add the direction, this direction comes from the joystick input. 

```cpp
if (newHeadX < 0 || newHeadX >= ROWSX || newHeadY < 0 || newHeadY >= ROWSY)
{
  game_over = true;
  return;
}

for (int i = 0; i < snake.length; i++)
{
  if (snake.segments[i].x == newHeadX && snake.segments[i].y == newHeadY)
  {
    game_over = true;
    return;
  }
}
```
these if statements are used to check for collisions with the game border and the segments of the snake itself

after this the code starts a big if statement for when an apple is eaten. in this if statement we have several important parts
```cpp
for (int i = snake.length; i > 0; i--)
  {
    snake.segments[i] = snake.segments[i - 1];
  }
```
this loop is used to set every segment to the segment in front of it when the snake gets an apple

```cpp
for (int i = 0; i < snake.length; i++)
      {
        if (snake.segments[i].x == apple.x && snake.segments[i].y == apple.y)
        {
          validPosition = false;
          break;
        }
      }
```
this loop checks the x and y positions of a newly generated apple with all segments of the snake, when the apple get created on a spot thats already in use, the boolean validPosition gets set to false and the proces of creating a new apple restarts.

### void readSensors()
this function is used to get sensor data from the joystick to give directions to the snake.
```cpp
if (vert < DOWNTHRES && snake.direction_y != -1)
  {
    snake.direction_x = 0;
    snake.direction_y = 1;
    totaldown++;
  }
```
in this code snippet you can see how the input from the joystick is handled. the smaller than 1000 is a countermeasure for stick drift. it ensures the snake doesnt move without being told to do so. it also counts the total times the function is called, this is used to display statistics at the end of the game

### void gameOverScreen()
this function is used to display a message when the game stops, it displays score and a big game over.

### void reset()
```cpp
snakeInit();
moveTime = millis();
```
this function updates the moveTime to the current time with millis(). this is used so the game knows when it needs to move the snake.

### void httpreq()
The httpreq function sends the snake’s movement statistics to a server using an HTTPS POST request. It first creates WiFi and HTTPS clients, then prepares a JSON object containing the number of times the snake moved up, down, left, and right. This JSON is converted into a string and sent over a secute HTTPS connection to the server. The function also prints the JSON to the serial monitor for debugging.

```cpp
HTTPClient httpClient;
httpClient.begin(client, url);
```
this bit of code is used to create a httpclient. this is then used to link a url to send the httprequest to.

```cpp
StaticJsonDocument<200> doc;
doc["totalup"] = totalup;
doc["totaldown"] = totaldown;
doc["totalleft"] = totalleft;
doc["totalright"] = totalright;
```
this bit of code creates a json document called doc. then it adds the totals to the json file.

```cpp
String jsonString;
serializeJson(doc, jsonString);
```
a string is created called jsonString. ater this the serialize Json puts the information from the doc into this string.
by doing this it makes it easier for the API to read.

```cpp
httpcode = httpClient.POST(jsonString);
```
this last bit of code sends the jsonString to the webpage(url).

### void startGame()
The startGame function initializes a new game by sending an HTTPS POST request to a server which in turn gets a game ID from a database. It also retrieves the server's response. These values are stored in player_id and game_id for use in the game. for more information on the code, see above(httpsreq)

### void webserver()
The webserver function listens for incoming connections on port 80. When a client connects, it reads the request and checks if the client has requested a specific endpoint (like "GET /debug"). Based on the request, the server either handles the request or responds with the corresponding information.

```cpp
WiFiClient client = server.available();
```
this code snippet checks if the server has a connection

```cpp
  if (client.available()) {
    char c = client.read();
    request += c;
    if (c == '\n') break;
  }
```
this part of the code puts the http request into a string named request.

```cpp
if (request.indexOf("GET /debug") >= 0) {
  debug();
}
```
the if statement checks if the request string contains a certain word or command and if it does it starts the debug
function

### void debug
The debug function is used for debugging purposes. It displays information on the OLED screen about the joystick's movements and button presses. It also provides visual feedback, guiding the user through various steps (e.g., pressing buttons, moving the joystick in different directions). After every action, it waits for user input before proceeding to the next step.

```cpp
while(digitalRead(BUTTON_1_PIN)){
  display.fillScreen(ILI9341_WHITE);
  display.display();
  delay(20);
}
```
this fills the entire display, this way you can see if a pixel is broken

```cpp
while (vert < UPTHRES){
  vert = analogRead(VERT_PIN);
  display.setCursor(0, 0);
  display.println("joystick omhoog");
  display.display();
}
```
this checks if the joystick can move upwards. this loop is copied for all directions

```cpp
while(digitalRead(BUTTON_1_PIN)){
  display.setCursor(0, 0);
  display.println("press button when");
  display.println("buzzer sounds");
  display.display();
  tone(BUZZER_PIN, 1000, 100);
}
```
this loop plays a sound on the buzzer, after this the user needs to press the button to continue.

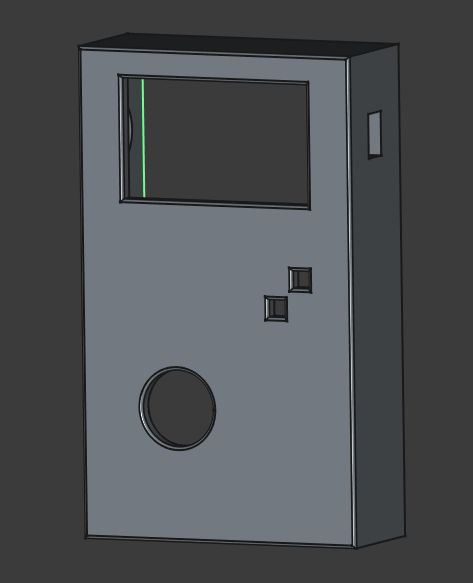
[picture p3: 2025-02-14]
docs/assets/designfrontpicture.png

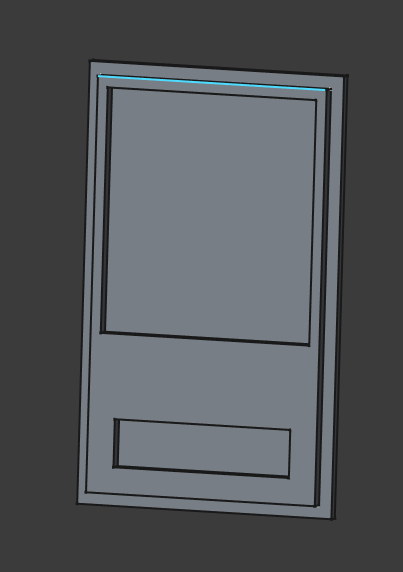
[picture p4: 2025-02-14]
docs/assets/designbackpicture.png

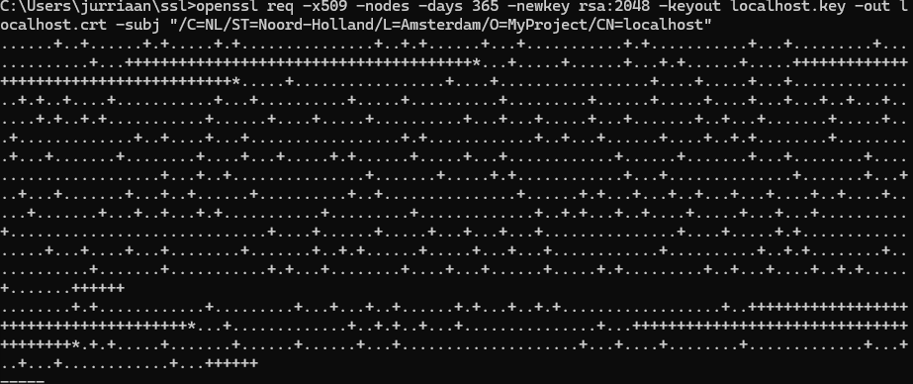
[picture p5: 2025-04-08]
docs/assets/key_generation.png

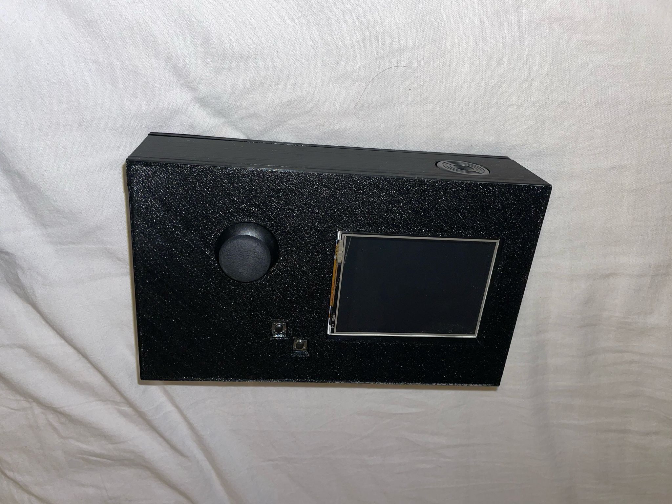
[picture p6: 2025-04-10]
docs/assets/prod_left.jpg

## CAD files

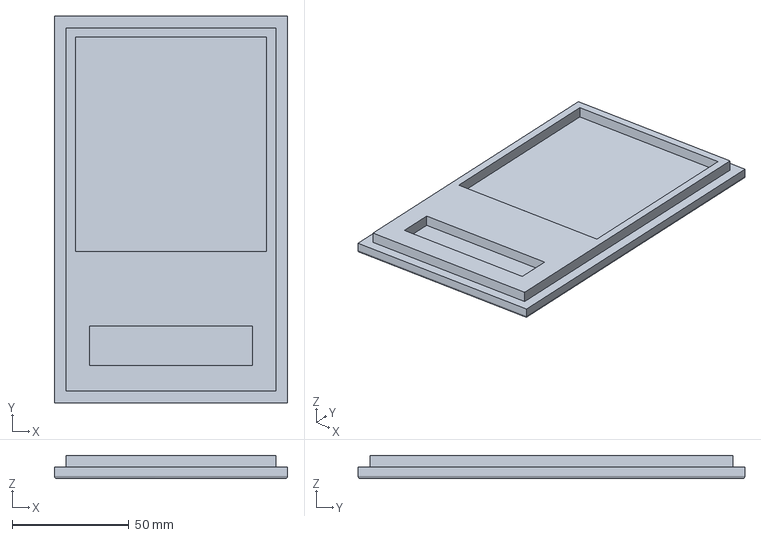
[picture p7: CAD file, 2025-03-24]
docs/uxd/blokboybackpanel.FCStd
100.0 x 166.0 x 10.0 mm

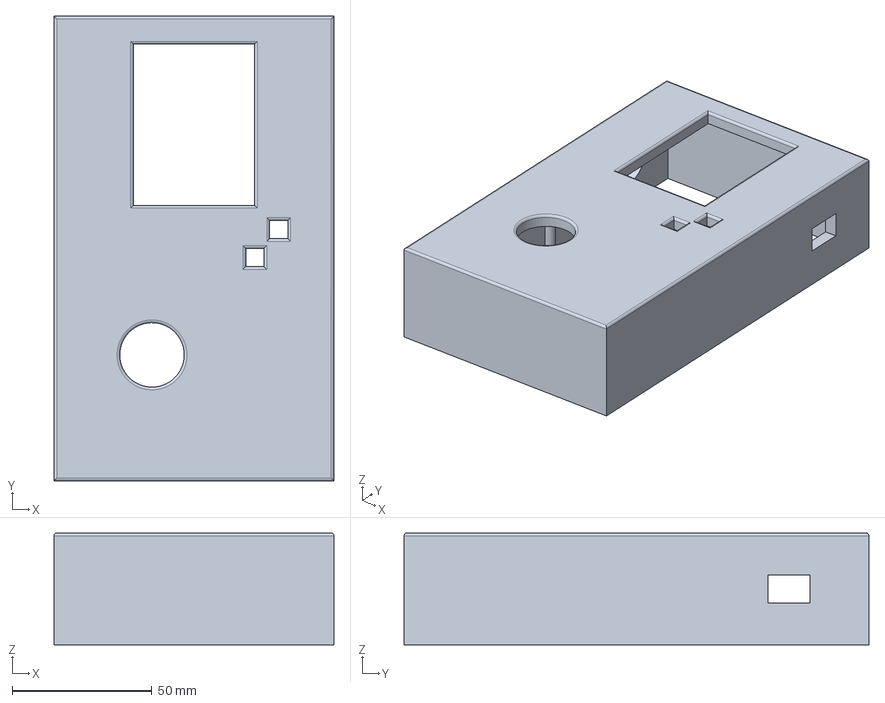
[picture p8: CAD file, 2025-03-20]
docs/uxd/blokboygamingdevice.FCStd
100.0 x 166.0 x 40.0 mm

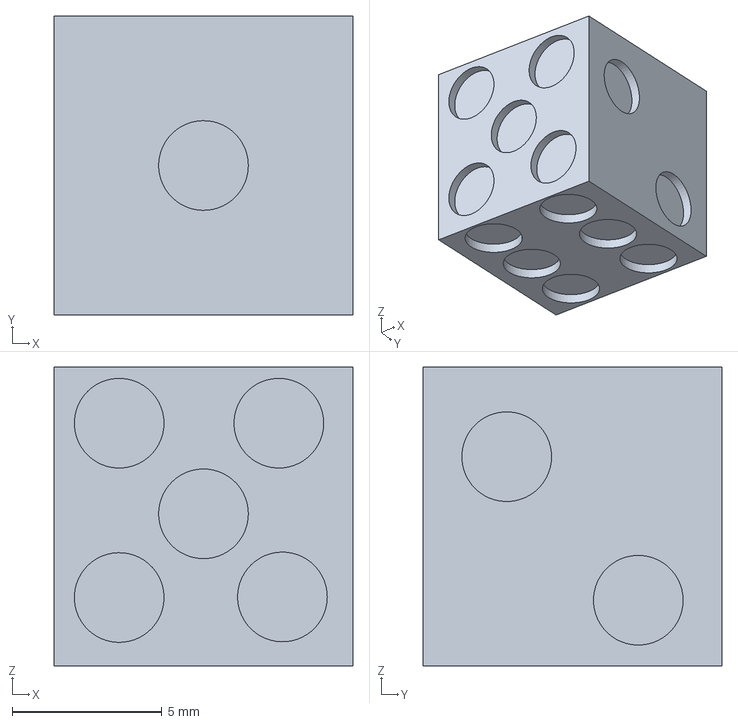
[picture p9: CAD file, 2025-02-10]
docs/uxd/dice3d.FCStd
10.0 x 10.0 x 10.0 mm

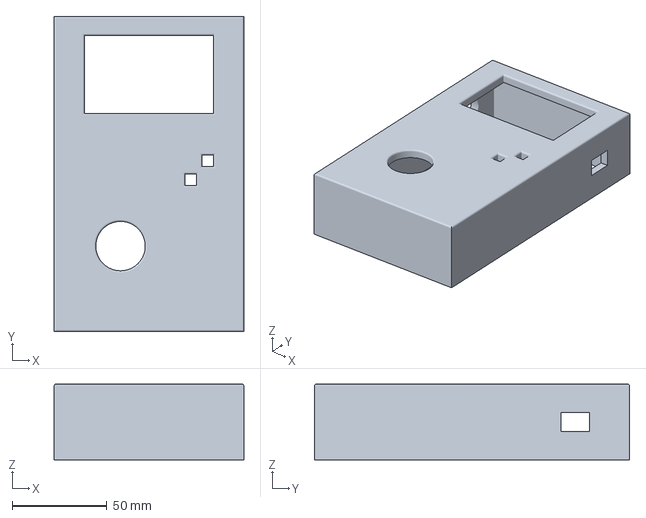
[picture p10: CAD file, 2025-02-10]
docs/uxd/blokboygamingdevice-Body-printable.3mf
100.0 x 166.0 x 40.0 mm

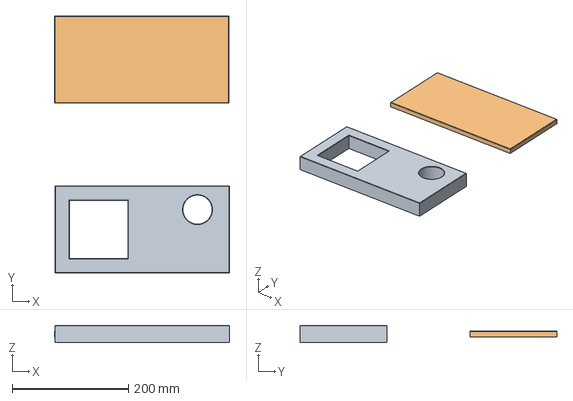
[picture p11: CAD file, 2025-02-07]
docs/uxd/first3ddesign.FCStd
301.0 x 442.0 x 30.0 mm

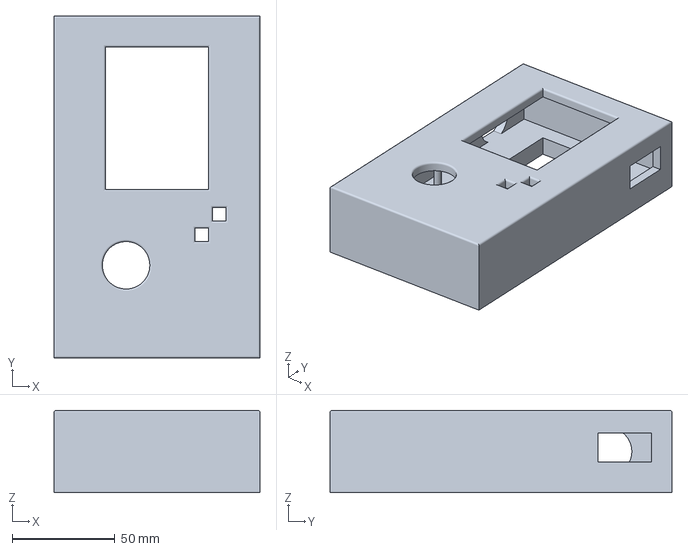
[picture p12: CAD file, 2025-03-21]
docs/uxd/blokboygamingdevice_screws-Body_v2.3mf
100.0 x 166.0 x 40.0 mm

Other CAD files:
docs/uxd/blokboybackpanel-Body001_v2.stl
docs/uxd/dice3d-Body.3mf
docs/uxd/blokboybackpanel-Body001-printable.3mf
docs/uxd/blokboygamingdevice_screws-Body_v4.stl
docs/uxd/blokboygamingdevice_screws.FCStd
docs/uxd/blokboygamingdevice_screws-Body_v3.stl
docs/uxd/blokboygamingdevice_screws-Body.3mf
docs/uxd/blokboygamingdevice_screws-Body_v2.stl

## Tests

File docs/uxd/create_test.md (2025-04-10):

# Create & Test

## test goal
the goal of this test is to check:
- if all components fit properly in the printed case
- if the joystick and buttons are comfortable to use
- if the screen is clearly visible during gameplay
- if the case feels solid and portable in the hand

these elements have the most impact on the final product because they directly influence usability, portability and durability.

## test setup
1. hold the device and comment on weight and grip
2. play a test version of the game and give feedback on controls and visibility

## test results
test subject peter
- didnt like the joystick that doest feel smooth
- the device is easy to handle and everything is in the correct place
- unclear buttons, what do they do
- takes a while for the device to start up and its unclear what the device is doing during that time
- the battery started to run out and the screen was barely visible

test subject ian
- the device fits well in the hand
- the joystick doesnt move well
- buttons are unclear

test subject koen
- the device weighs less than expected
- the display isnt level
- the joystick gets stuck sometimes
- the buttons are very unclear

## conclusion
### conclusions (based on user tests)

after running the tests with three users, the following key issues were observed:

- the joystick is not smooth and sometimes gets stuck (reported by all three users)
- the function of the buttons is unclear (reported by all users)
- the screen visibility is poor when the battery runs low (1 user) and the display is not level (1 user)
- there is no clear feedback during startup, making the device feel unresponsive (1 user)

positive feedback:
- all users said the device fits well in the hand
- the layout of the controls is logical and easy to reach
- the device is lightweight and comfortable to hold

### issues

| issue | priority | reason |
|---|---|---|
| joystick is not smooth or gets stuck | high | affects gameplay and overall UX |
| button functions are unclear | high | creates confusion in basic interaction |
| screen not level / low visibility | medium | impacts visibility but only in some cases |
| no startup feedback | medium | affects perceived quality and responsiveness |

## optimalization
based on the user test results, several optimisations need to be made to improve the overall usability and physical interaction of the device. these will however not me made on time for the product market.

- joystick movement improvement: the joystick gets stuck and does not move smoothly. the hole should be increased by 0.4 mm and the hole should have smoother edges.  

- button clarity: users found the button functions unclear. symbols or labels should be on or next to the buttons in the next iteration.  

- screen level adjustment: the screen is not level with the case because of the pins, to fix this an extra hole for the pins should be made.

- low visibility: after playing the game for a while the battery starts to get empty, to fix this a charger for the battery is necessary.

## files
all files are stored in the uxd map of gitlab, more about which files are used can be found in concept design.

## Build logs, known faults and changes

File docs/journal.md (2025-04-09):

# Learning journal

## feedback per week

## week 2

### things i learned this week
this week i learned how to 3d design and make a print. i made my own design for my handheld gaming device and we had a class about 3d printing where we needed to design and print a dice. before we could print it we had to initialize the settings for the 3d printer. this was done with a paper sheet and the springs underneath the 3d printer.
in my first try the dice was a succes, but there were some things i could inprove, like where i needed to put circles in combination with edges.

### feedback
feedback from ian: 

use more comments and a question about values's

feedback from peter:

code is good, nothing to say about code

feedback from nino:

code looks good, you could use more comments to make the code a bit easier to understand.

### what to change to be better?
i need to start using comments. at first i thought i would write the code first and add comments later but i noticed this makes it more difficult for myself and for readability for others. so in the class free week i will be adding comments to all my code and get everything updated for better readability.

## week 3

### things i learned this week
this week i did a workshop about lasercutting, i learned what to do with several different speeds, strengths and intervals. i also learned about the safety measures. after the workshop we had the time to make something ourselves and with the other classmates who were doing the workshop i created a design with several round curves and an infill in the design. by using the already given variables the design had a very clean cut.

in week 2 i started with the backend of my website, i created a GET.php file to get information from the database. i also created an INSERT. this is used to put stuff into the database. creating this was rather difficult because i had never really worked with php and SQL before. this meant i had to start from scratch. luckily the internet is a big help with this.

### feedback

## week 4

### HTML
this week i learned more about web development. HTML helped me build the basic structure of the page. I used different tags to organize my content and added important elements like a button and a table that shows the scores that are fethced from my database scores. I also learned how to connect an external JavaScript file and a CSS file in the head section. 

### CSS
with CSS i can control how the page looks. I set up fonts, changed background colors, and made sure that different parts of the page have the right spacing. I also tried to make sure the page is responsive, so it looks good on both big screens and small screens.

### JavaScript
JavaScript made the page interactive. For example, I used the fetch function to get data from my database, then created table rows and columns to display data. I also added an event listener to the button, so that when you click it, it sends a request to the ESP32 for debugging.

### Problems
while working on web development i ran into a problem i had some difficulties solving. the css wasnt loading on the page. i needed to clear my cache everytime i wanted to check the css. by doing a little research i found out i could use something called a cache buster. after adding this 

### feedback

## week 5
### JavaScript
i used JavaScript to make it possible for the website to communicate with the ESP32. I used the fetch function to send a request to the ESP32's local IP address. This request asks the ESP32 to execute a command, and I logged the response in the console to check if it was working. I also learned how to handle errors if the ESP32 was not responding.

### ESP32
ESP32 as a webserver. The ESP32 runs a small server that listens for requests from my website. When the site sends a request to /command, the ESP32 processes it and sends back a response.

### feedback

## week 6
### 10/3/25
my goal for today is to write more in my learning journal, i also want to create a debugging function for the ESP32, so i can be able to test the sensors for my project if necessary.

done: i have written the most important things ive learned in the last few weeks for my learning journal. 

### 12/3/25
my goal for today is to get to know more about architecture diagrams, how to create them and why you use them.

i learned how to use plantuml for automatic generation of architecture diagrams, i added all components for the esp32, i added the API files used for fetching data and the files used in the frontend. 

### 13/3/25
my goal for today is to create a working debug function which you can activate through the website.

today i fixed my debug function, it didnt work because of a few small bugs i hadnt thought about. like the fact that i needed to use display.display() and 
display.cleardisplay() after everytime i wanted to do something. i also ran into the problem that when you clicked the button for the last time in the debug, it automatically started a new game, it did this because it registered several clicks. to fix this i added a delay.

### 14/3/25
my goal for today is to write code for the ili9341, a bigger screen that will be an upgrade to the ssd1306

today i tested code fo the ili9341 in wokwi, the code worked, now i need to wait for the actual display to arrive so i can test it. i also updated the 3d design to fit the actual screen and not the entire pcb. 
## week 7
### 17/3/25
my goal for today is to start printing my 3d print in the makerslab. this will be my first time printing something i designed myself so there will probably be some problems. when i start my 3d print i will work on documentation.

today i started printing my first real 3d print with the help of a teacher in the makerslab. the first few layers looked very good and tomorrow i will see how it turned out. i also started working on my research question. this took a very long time because i didnt know what i wanted to do. at last i came up with the question: how do i make my entire system safer. i want to make every part of the system safer for now but first i will need to check with a teacher to ask if this is correct question or if it might be too big

### 18/3/25
my goal for today is to get my 3d print and test if the components i already have fit, and if not(probably), what i need to change in my next iteration to make it fit.

necessary changes to 3d design:
- bigger hole for piezo buzzer
- better buttons and bigger holes for buttons
- smaller hole for joystick
- some way to hold joystick in place
- some way to hold display in place

today i have learned a lot about 3d design and the things you dont think about before deisgning someting. my design was good but most of my meausurements were not acurate enough. because of this most parts dont fit or dont have a way to stay in place. for testing purposes i carved out a little plc to try and get the piezo buzzer to fit. this is however too much work and isnt smart to do for every part. that is why i will need to work on a better design and start a second iteration of the front of my design

### 20/3/25
my goal for today is to learn how to use the bambu printers in the makerslab, the difference between the ultimakers and the bambu's is that they are quicker. this means i can 3d print faster. 

unfortunately the bambu printers were taken, and i wont be able to use and learn about them today. however im very confident that this will not be my last iteration of 3d printing. i will be using the ultimaker 2+ for today and check on the progress tomorrow.

### 21/3/25
my goal for today is to use the bambu 3d printer. i have had an explanation on how everything works so i think i can start it all by myselft for now. the ili9341 also arrived(broken screen unfortunately), and i would really like to integrate the display into my prototype.

my print looks very good, unfortunately the screen doesnt fit well enough and the joystick screw pillars arent palced correctly. also the on off switch hole is too small i have now changed these things and will start with my next iteration.

today i learned a lot about 3d printing, my print went wrong twice because one of the printers wasnt leveled correctly. luckily i followed the advice of the teachers at the makers lab to make sure to stay with the print for at least the first layer. because of this i made sure that i started a new print within 15 minutes. i also started with the bigger ili9341 display. i tested code that i made within a simulator and this worked. it did have some problems with the backlight, this was white which made the display flicker. after turning it off the "hello world" worked perfectly. now i only need to integrate it into my project. i have planned to do this this weekend or maybe the monday after this weekend.
## week 8
### 26/3/25
my goal for today is to get my SPI display to work, right now it works but the framerate is bad which makes it look glitchy.

yesterday i fixed my SPI display, this took a very long time because my entire code needed upgrades and changes and i didnt know which changes i needed. after a long while i finally found what i had to change, instead of clearing the entire screen everytime i wanted to update something i need to only clear the pixels that werent necessary anymore. when i cleared the entire screen the display started flickering, this was because the SPI is slower than the I2C i used before this. now i have updated the code to make it work the way i said before.

## week 9
this week i did a lot of documentation, so there is not a lot i can add to my learning journal
## week 10
### 8/4/25
today i learned how to install and use https, this is done to increase the safety of the messages between server and client by encoding the message. at first it was a little bit difficult, i followed an website's step by step instructions but this didnt work correctly. So after this i tried to use chatgpt, this helped me tremendously because it could immediatly pinpoint where i went wrong, like the fact that i needed the openssl software in my PATH. and the fact that i made some slight mistakes in my nginx.conf file, because of this i could pretty easily upgrade to https. after this i also used wireshark to test the encoded message, i had not done this for a pretty long time as well so i had to find out how all of this worked, this was however pretty easy.

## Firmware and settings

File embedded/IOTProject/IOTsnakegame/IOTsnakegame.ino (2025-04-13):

/*
 * Author: Jurriaan Egmond
 * Date: 2025
 * License: MIT
 *
 * Description:
 *   This file contains the main code for the Snake game on an ESP32.
 *   It handles the display (ILI9341), sensor input (joystick and buttons),
 *   and secure communication (HTTPS) with a backend server. Functions 
 *   include reading joystick data, updating the Snake position, drawing 
 *   graphics on the display, and sending/receiving data over WiFi.
 *
 * MIT License
 * 
 * Copyright (c) 2025 Jurriaan Egmond
 * 
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
 * THE SOFTWARE IS PROVIDED "AS IS", WITHOUT WARRANTY OF ANY KIND, EXPRESS OR
 * IMPLIED, INCLUDING BUT NOT LIMITED TO THE WARRANTIES OF MERCHANTABILITY,
 * FITNESS FOR A PARTICULAR PURPOSE AND NONINFRINGEMENT. IN NO EVENT SHALL THE
 * AUTHORS OR COPYRIGHT HOLDERS BE LIABLE FOR ANY CLAIM, DAMAGES OR OTHER
 * LIABILITY, WHETHER IN AN ACTION OF CONTRACT, TORT OR OTHERWISE, ARISING FROM,
 * OUT OF OR IN CONNECTION WITH THE SOFTWARE OR THE USE OR OTHER DEALINGS IN THE
 * SOFTWARE.
 */

#include <Wire.h>
#include <Arduino.h>
#include <Adafruit_GFX.h>
#include <Adafruit_ILI9341.h>
#include <WiFi.h>
#include <HTTPClient.h>
#include <WiFiClientSecure.h>
#include <ArduinoJson.h>
#include <WiFiManager.h>

// joystick pins
#define VERT_PIN 18
#define HORZ_PIN 17
#define SEL_PIN 11

// joystick constants
#define UPTHRES 3500
#define DOWNTHRES 500
#define LEFTTHRES 500
#define RIGHTTHRES 3500

// ili9341 pins and defines
#define TFT_CS   10
#define TFT_DC   9
#define TFT_RST  3
#define TFT_CLK  4
#define TFT_MOSI 5
#define DISPLAY_WIDTH 240
#define DISPLAY_HEIGHT 320

// button pins
#define BUTTON_1_PIN 6
#define BUTTON_2_PIN 7

// max lenght of the snake
#define MAX_LENGTH 100

// buzzer pin
#define BUZZER_PIN 12

// size of the game, display is 320 by 240, game has blocks size of 8
// so 240 and 320 divided by 8
#define BLOCKSIZE 8
#define ROWSX 30
#define ROWSY 40

// struct for creating snakesegments in another struct
struct SnakeSegment {
  int x;
  int y;
};

// struct for keeping information on the snake
struct Snake {
  SnakeSegment segments[100];
  int length;
  int direction_x;
  int direction_y;
};

// struct for keeping information about the apple
struct Apple {
  int x;
  int y;
};

Snake snake;
Apple apple;

bool game_over;

// variables for the game
int score = 0;
int totalleft;
int totalright;
int totalup;
int totaldown;

// variables needed for the game
unsigned long moveTime = 0;
const unsigned long moveSpeed = 200;

// variable for http request
int httpCode;

// variables for information about the game
int player_id = 0;
int game_id = 0;

// variables for tail
int oldTailX = -1;
int oldTailY = -1;

WiFiServer server(80);

// ip's school
// const char* url = "https://145.92.189.65/api/insert.php";
// const char* starturl = "https://145.92.189.65/api/start_game.php";

// // // ip's home
const char *url = "https://192.168.178.61/api/insert.php";
const char* starturl = "https://192.168.178.61/api/start_game.php";

// initialization of the display
Adafruit_ILI9341 display = Adafruit_ILI9341(TFT_CS, TFT_DC, TFT_RST);

void snakeInit();
void createGame();
void drawSnake();
void readSensors();
void gameOverScreen();
void reset();
void httpreq(int game_id, int totalup, int totaldown, int totalleft, int totalright, int score);
void startGame();
void webserver();
void debug();

void setup() {
  Serial.begin(115200);

  //seeding the random generator with the time
  randomSeed(micros());

  // not used
  // WiFi.begin(ssid, password);
  // while (WiFi.status() != WL_CONNECTED) {
  //   delay(250);
  //   Serial.print(".");
  // }

  WiFiManager wifiManager;
  // start wifi
  if (!wifiManager.autoConnect("ESP32-Setup")) {
    Serial.println("Failed to connect, restarting...");
    delay(3000);
    ESP.restart();
  }

  Serial.println("Connected to WiFi!");
  Serial.print("ESP32 IP Address: ");
  Serial.println(WiFi.localIP());

  server.begin();
  Serial.println("Webserver started");
  SPI.begin(TFT_CLK, -1, TFT_MOSI);
  display.begin();

  // set pins for buttons
  pinMode(BUTTON_1_PIN, INPUT_PULLUP);
  pinMode(BUTTON_2_PIN, INPUT_PULLUP);

  // set pins for joystick
  pinMode(VERT_PIN, INPUT);
  pinMode(HORZ_PIN, INPUT);
  pinMode(SEL_PIN, INPUT_PULLUP);

  // set pin for buzzer
  pinMode(BUZZER_PIN, OUTPUT);

  // not used
  // start connection with display and check if i2c connection works
  // if (!display.begin(SSD1306_SWITCHCAPVCC, 0x3C)) {
  //   Serial.println("OLED not found");
  //   while (true)
  //     ;
  // }

  // initialize important things for display
  //display.clearDisplay();
  display.setTextSize(1);
  display.setTextColor(ILI9341_WHITE);
  display.fillScreen(ILI9341_BLACK);

  //initialize snake
  snakeInit();
}

/// @brief Initializes the snake game by resetting game variables.
/// This function sets the initial values for the snake game
void snakeInit() {

  startGame();
  // set all the variables to 0 or false
  game_over = false;
  score = 0;
  totalup = 0;
  totaldown = 0;
  totalleft = 0;
  totalright = 0;

  // set length of initial snake
  snake.length = 1;

  // set first snake segments on random place
  snake.segments[0].x = random(0, ROWSX);
  snake.segments[0].y = random(0, ROWSY);

  // no movement when starting
  snake.direction_x = 0;
  snake.direction_y = 0;

  // set the first apple on a random x and y
  apple.x = random(0, ROWSX);
  apple.y = random(0, ROWSY);
}

/// @brief puts the elements needed for the game on the display.
/// This function clears the screen and then draws the initial apple and the snake
/// on the display using their x and y positions.
void createGame() {
  //display.clearDisplay();
  // draw the border for the game
  display.drawRect(0, 0, 240, 320, ILI9341_WHITE);

  // converts apple x and y position to usable positions for the display
  int applex = (apple.x * BLOCKSIZE);
  int appley = (apple.y * BLOCKSIZE);

  // draws apples as a square on the display
  display.fillRect(applex, appley, BLOCKSIZE, BLOCKSIZE, ILI9341_RED);

  // loop through the snake segments and convert and fill them the same way as the apple
  for (int i = 0; i < snake.length; i++) {
    int x = snake.segments[i].x * BLOCKSIZE;
    int y = snake.segments[i].y * BLOCKSIZE;
    display.fillRect(x, y, BLOCKSIZE, BLOCKSIZE, ILI9341_GREEN);
  }

  // display everything on the screen
  //display.display();
}

/// @brief Moves the snake forward and checks for collisions.
/// This function updates the snake's position, handles apple eating,
/// and checks for collisions with the walls or the snake's own segments.
void drawSnake() {
  if (snake.direction_x == 0 && snake.direction_y == 0) {
    return;
  }

  if (snake.direction_x == 1) totalright++;
  else if (snake.direction_x == -1) totalleft++;
  else if (snake.direction_y == 1) totaldown++;
  else if (snake.direction_y == -1) totalup++;

  // remember old tail x and y
  oldTailX = snake.segments[snake.length - 1].x;
  oldTailY = snake.segments[snake.length - 1].y;
  
  // calculate new snake head
  int newHeadX = snake.segments[0].x + snake.direction_x;
  int newHeadY = snake.segments[0].y + snake.direction_y;

  // check for boundaries 
  if (newHeadX < 0 || newHeadX >= ROWSX || newHeadY < 0 || newHeadY >= ROWSY) {
    game_over = true;
    return;
  }

  // check for other collision
  for (int i = 0; i < snake.length; i++) {
    if (snake.segments[i].x == newHeadX && snake.segments[i].y == newHeadY) {
      game_over = true;
      return;
    }
  }

  // check if the snake eats an apple
  bool ateApple = (newHeadX == apple.x && newHeadY == apple.y);

  if (ateApple) {
    tone(BUZZER_PIN, 1000, 30);
    // all segments of the snake go forward
    for (int i = snake.length; i > 0; i--) {
      snake.segments[i] = snake.segments[i - 1];
    }
    // new snakehead position, length and score
    snake.segments[0].x = newHeadX;
    snake.segments[0].y = newHeadY;
    snake.length++;
    score++;

    // create new apple
    bool validPosition = false;
    while (!validPosition) {
      apple.x = random(0, ROWSX);
      apple.y = random(0, ROWSY);
      validPosition = true;
      // check if the apple is in a correct place
      for (int i = 0; i < snake.length; i++) {
        if (snake.segments[i].x == apple.x && snake.segments[i].y == apple.y) {
          validPosition = false;
          break;
        }
      }
    }
  } else {
    // if no apple is eaten palce all segments of the snake forward
    for (int i = snake.length - 1; i > 0; i--) {
      snake.segments[i] = snake.segments[i - 1];
    }
    snake.segments[0].x = newHeadX;
    snake.segments[0].y = newHeadY;
  }

  // remove old tail
  if (!ateApple) {
    display.fillRect(oldTailX * BLOCKSIZE, oldTailY * BLOCKSIZE, BLOCKSIZE, BLOCKSIZE, ILI9341_BLACK);
  }

  // draw new head
  display.fillRect(snake.segments[0].x * BLOCKSIZE, snake.segments[0].y * BLOCKSIZE, BLOCKSIZE, BLOCKSIZE, ILI9341_GREEN);

  // draw new apple
  if (ateApple) {
    display.fillRect(apple.x * BLOCKSIZE, apple.y * BLOCKSIZE, BLOCKSIZE, BLOCKSIZE, ILI9341_RED);
  }
}

/// @brief reads the sensors and updates the direction of the snake
/// this function converts the analog inputs from the sensors to usable
/// data the game can use to go towards any direction
void readSensors() {

  // variables for the reading of the joystick
  int vert = analogRead(VERT_PIN);
  int horz = analogRead(HORZ_PIN);

  // not used
  // bool selPressed = digitalRead(SEL_PIN) == LOW;
  // bool button1 = !digitalRead(BUTTON_1_PIN);
  // bool button2 = !digitalRead(BUTTON_2_PIN);


  // if statement to check if the joystick is going down
  if (vert < DOWNTHRES && snake.direction_y != -1) {
    // updates direction
    snake.direction_x = 0;
    snake.direction_y = 1;
  }
  // if statement to check if the joystick is going up
  else if (vert > UPTHRES && snake.direction_y != 1) {
    // updates direction
    snake.direction_x = 0;
    snake.direction_y = -1;
  }

  // if statement to check if the joystick is going left
  if (horz < LEFTTHRES && snake.direction_x != 1) {
    // updates direction
    snake.direction_x = -1;
    snake.direction_y = 0;
  }
  // if statement to check if the joystick is going right
  else if (horz > RIGHTTHRES && snake.direction_x != -1) {
    // updates direction
    snake.direction_x = 1;
    snake.direction_y = 0;
  }
}

/// @brief puts a big game over on the display
void gameOverScreen() {
  display.fillScreen(ILI9341_BLACK);
  //display.clearDisplay();
  // size of the text
  display.setTextSize(3);
  // startpoint for the text
  display.setCursor(40, 160);
  display.print("Game Over");
  display.setTextSize(2);
  display.setCursor(60, 200);
  display.print("Score: ");
  display.print(score);
  //display.display();
}

/// @brief this resets the game
void reset() {
  display.fillScreen(ILI9341_BLACK);
  snakeInit();
  // sets start time for momvement time for the next game
  moveTime = millis();
}


/// @brief Sends a JSON HTTPS request with movement statistics.
/// This function sends a HTTPS POST request containing the total movement
/// stats of the snake during a game
/// @param game_id ID created by database, used as foreign keys for.
/// @param totalup The number of times the snake moved up.
/// @param totaldown The number of times the snake moved down.
/// @param totalleft The number of times the snake moved left.
/// @param totalright The number of times the snake moved right.
/// @param score The amount of points gotten in a game.
void httpreq(int game_id, int totalup, int totaldown, int totalleft, int totalright, int score) {

  // create clients for wifi and http
  WiFiClientSecure client;
  HTTPClient httpClient;

  // ignores unsafe(self generated)
  client.setInsecure();

  // initialize http client with url
  httpClient.begin(client, url);

  // set the content to send to json
  httpClient.addHeader("Content-Type", "application/json");

  // create json document with necessary information
  StaticJsonDocument<200> doc;
  doc["game_id"] = game_id;
  doc["totalup"] = totalup;
  doc["totaldown"] = totaldown;
  doc["totalleft"] = totalleft;
  doc["totalright"] = totalright;
  doc["score_value"] = score;
  // create string called jsonstring
  String jsonString;
  // convert the json (doc) to a string (jsonstring)
  serializeJson(doc, jsonString);

  Serial.print("Verstuurde JSON: ");
  Serial.println(jsonString);

  // send the json string
  httpCode = httpClient.POST(jsonString);

  if (httpCode > 0) {
    // print response code from http POST
    Serial.println(httpCode);
  } else {
    Serial.print("POST failed: ");
    Serial.println(httpCode);
  }
}

/// @brief sends an http request to get necessary values to start a game
/// This function sends a HTTP request to a webpage. this webpage then interacts with the API 
/// the API then creates a new database addition and sends the ID's back
void startGame() {
  if (WiFi.status() != WL_CONNECTED) {
    Serial.println("WiFi not connected!");
    return;
  }

  WiFiClientSecure client;
  HTTPClient http;
  client.setInsecure();
  http.begin(client, starturl);
  http.addHeader("Content-Type", "application/json");

  //create json payload
  StaticJsonDocument<200> doc;
  doc["generate"] = 1;
  String jsonString;
  serializeJson(doc, jsonString);

  // send http post
  int httpResponseCode = http.POST(jsonString);
  if (httpResponseCode > 0) {
    String response = http.getString();
    Serial.print("Response from startGame: ");
    Serial.println(response);

    // parse json
    StaticJsonDocument<200> responseDoc;
    DeserializationError error = deserializeJson(responseDoc, response);
    if (!error && responseDoc["status"] == "success") {
      // player_id en game_id uitlezen
      player_id = responseDoc["player_id"] | 0;
      game_id = responseDoc["game_id"] | 0;
    } else {
      Serial.println("Failed to parse JSON or status != success.");
    }
  } else {
    Serial.print("POST failed, error code: ");
    Serial.println(httpResponseCode);
  }
  http.end();
}

/// @brief Starts a web server that listens for incoming connections.
///  If a client sends a request containing "GET /debug", the debug() function is triggered.
void webserver() {
  // check for connections to server
  WiFiClient client = server.available();

  if (client) {
    Serial.println("New Client connected!");
    String request = "";

    // if the client is connected stay in the loop
    while (client.connected()) {
      if (client.available()) {
        // read one character and add it to the request string
        char c = client.read();
        request += c;
        if (c == '\n') break;
      }
    }

    //check if the request string contains the command necessary to start debug function
    if (request.indexOf("GET /debug") >= 0) {
      debug();
    }
    Serial.println("Client Request: ");
    Serial.println(request);
    client.stop();
    Serial.println("Client disconnected.");
    gameOverScreen();
  }
}

/// @brief Runs a full hardware debug function for the joystick, button, display, and buzzer.
/// Guides the user through debug to verify each component works correctly.
void debug(){
  int vert = analogRead(VERT_PIN);
  int horz = analogRead(HORZ_PIN);
  //display.clearDisplay();
  display.fillScreen(ILI9341_BLACK);
  display.setCursor(0, 0);
  display.println("starting debug");
  //display.display();
  delay(5000);
  //display.clearDisplay();
  display.fillScreen(ILI9341_BLACK);

  // Show initial debug message
  display.setCursor(0, 0);
  display.println("press button to continue");
  //display.display();
  delay(5000);
  // Fill the screen white to check for broken pixels
  while(digitalRead(BUTTON_2_PIN)){
    //display.display();
    delay(20);
  }
  // clear the screen
  display.fillScreen(ILI9341_BLACK);
  //display.clearDisplay();

  // check for joystick movement
  while (vert < UPTHRES){
    vert = analogRead(VERT_PIN);
    display.setCursor(0, 0);
    display.println("joystick omhoog");
    //display.display();
  }
  display.fillScreen(ILI9341_BLACK);
  //display.clearDisplay();
  while (vert > DOWNTHRES){
    vert = analogRead(VERT_PIN);
    display.setCursor(0, 0);
    display.println("joystick omlaag");
    //display.display();
  }
  display.fillScreen(ILI9341_BLACK);
  //display.clearDisplay();
  while (horz > LEFTTHRES){
    horz = analogRead(HORZ_PIN);
    display.setCursor(0, 0);
    display.println("joystick links");
    //display.display();
  }
  display.fillScreen(ILI9341_BLACK);
  //display.clearDisplay();
  while (horz < RIGHTTHRES){
    horz = analogRead(HORZ_PIN);
    display.setCursor(0, 0);
    display.println("joystick rechts");
    //display.display();
  }
  display.fillScreen(ILI9341_BLACK);
  //display.clearDisplay();
  // check for buzzer sounds
  while(digitalRead(BUTTON_2_PIN)){
    display.setCursor(0, 0);
    display.println("press button when");
    display.println("buzzer sounds");
    //display.display();
    tone(BUZZER_PIN, 1000, 100);
  }
  display.fillScreen(ILI9341_BLACK);
  delay(1000);
}

void loop() {
  if (!game_over) {
    readSensors();
    httpCode = 0;
    if (millis() - moveTime >= moveSpeed) {
      drawSnake();
      moveTime = millis();
    }

    createGame();
  } else {
    gameOverScreen();
    // used for debugging
    //Serial.printf("\n%d %d %d %d \n", totalup, totaldown, totalleft, totalright);
    while(digitalRead(BUTTON_1_PIN)){
      if (httpCode != 200) {
        httpreq(game_id, totalup, totaldown, totalleft, totalright, score);
      }
      webserver();
    }  
    reset();
  }
}

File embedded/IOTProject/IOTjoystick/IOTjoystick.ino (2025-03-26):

#define VERT_PIN 18
#define HORZ_PIN 17


void setup() {
  Serial.begin(115200);
  pinMode(VERT_PIN, INPUT);
  pinMode(HORZ_PIN, INPUT);
  //pinMode(SEL_PIN, INPUT_PULLUP);
}

void loop() {
  int vert = analogRead(VERT_PIN);
  int horz = analogRead(HORZ_PIN);
  //bool selPressed = digitalRead(SEL_PIN) == LOW;
  Serial.println(vert);
  Serial.println(horz);
  Serial.println(" ");
  delay(100);
}

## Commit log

2025-02-03 added initial arduino ide file for the iotproject
2025-02-06 added first 3d design for practice. added some lines for the snakegame, added a little documentation
    [first3ddesign.FCStd]
2025-02-06 added 3d design scaled to components.
    [blokboybackpanel.FCStd, blokboygamingdevice.FCStd, first3ddesign.FCStd]
2025-02-07 added a few changes for 3d, created a database and php scripts to connect to it and to add something into the database
    [blokboybackpanel.FCStd, first3ddesign.FCStd]
2025-02-09 added hole for on off button and hole for buzzer in 3d design
    [blokboybackpanel.FCStd, blokboygamingdevice.FCStd]
2025-02-10 added 3d printable dice for testing and printed this.
    [blokboybackpanel-Body001-printable.3mf, blokboygamingdevice-Body-printable.3mf, dice3d-Body.3mf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]
2025-02-10 added code for piezo buzzer
    [dice3d.FCStd]
2025-02-10 created readSensor function and moved the current code from the loop to it
2025-02-11 added last function to really play the game. still needs a little fixing. also fixed the game over screen so you can also see your score
    [IOTsnakegame.ino]
2025-02-12 added code for mac addres esp32 s3 wroom ( code is copied from the internet)
2025-02-12 added code to connect esp with wifi and added a wifi checker file for esp32 s3 wroom
2025-02-12 first use of Json for connection between esp32 and php api(php api hasnt been made yet)
2025-02-13 added first api endpoint and added first esp32 code to send to api(not working yet)
    [IOTdbconnection.ino, checkwificonnectionesp32s3wroom.ino]
2025-02-13 added working code on the backend and on the esp32 to use the api and get information into the database
2025-02-14 added fritzing file and picture of prototype
    [fritzing file prototype.fzz]
2025-02-14 added bill of materials for prototype
2025-02-28 changed name of file and added comments to INSERT API
2025-03-03 added error handler for http requests and added line around the game
    [IOTsnakegame.ino]
2025-03-03 added try catch to INSERT API, and added second statement for the score
2025-03-07 added button in html and css for the button
2025-03-07 added necessary code to use button
2025-03-10 added information about the esp32 as a webserver to learning journal
2025-03-13 fixed display bug and button bug
    [IOTsnakegame.ino]
2025-03-14 added bigger screen (2.8inch instead of 2.2)
    [blokboygamingdevice.FCStd]
2025-03-14 changed code for testing of bigger (2.8 inch) screen
    [blokboygamingdevice.FCStd]
2025-03-16 small changes to 3d design
    [blokboybackpanel.FCStd]
2025-03-19 resizing of components in 3d design
    [blokboygamingdevice.FCStd]
2025-03-19 added screw holes for joystick and switched around the display
    [blokboygamingdevice.FCStd]
2025-03-20 added goal to learning journal
    [blokboygamingdevice.FCStd, blokboygamingdevice_screws-Body.3mf, blokboygamingdevice_screws.FCStd]
2025-03-21 added important changes to design
    [blokboygamingdevice_screws.FCStd]
2025-03-21 changed some values for necessary components in 3d design
    [blokboygamingdevice_screws-Body_v2.3mf, blokboygamingdevice_screws-Body_v2.stl, blokboygamingdevice_screws.FCStd]
2025-03-21 changed code for display to have black backlight instead of white
    [blokboybackpanel-Body001_v2.stl, blokboybackpanel.FCStd]
2025-03-21 changed on off hole, changed screw pilars for joystick
    [blokboygamingdevice_screws.FCStd]
2025-03-21 made the hole for the display bigger
    [blokboygamingdevice_screws.FCStd]
2025-03-21 made the joystick hole bigger
    [blokboygamingdevice_screws.FCStd]
2025-03-21 added to learning journal
    [blokboygamingdevice_screws-Body_v3.stl]
2025-03-22 first integration of ili display into game code
    [blokboybackpanel.FCStd, blokboygamingdevice_screws.FCStd]
2025-03-24 next iteration frontpanel
    [blokboybackpanel.FCStd, blokboygamingdevice_screws-Body_v4.stl, blokboygamingdevice_screws.FCStd]
2025-03-24 added changes for quicker SPI
2025-03-24 changes to game for SPI
2025-03-26 first working game without display problems with SPI, needs a lot of fixing
    [IOTsnakegame.ino]
2025-03-26 fixed glitching SPI display during game over screen
    [IOTsnakegame.ino]
2025-03-27 added text for current design
2025-03-27 added fixes to debug function
    [IOTsnakegame.ino]
2025-03-31 added http wireshark picture to assets and research
2025-03-31 added info for screenshot wireshark
2025-03-31 added more wireshark pictures to research
2025-04-09 added to bom, created Wiring diagram
2025-04-09 added intro to wiring diagram
